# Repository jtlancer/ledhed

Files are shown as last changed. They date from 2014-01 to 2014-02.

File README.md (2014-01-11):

##Snoozerly Dawn Simulator
An Arduino-controlled combination [Ok to Wake](http://www.amazon.com/s/ref=nb_sb_noss?url=search-alias%3Daps&field-keywords=child%20ok%20to%20wake) alarm clock, [dawn simulator](http://www.amazon.com/Sunrise-Therapy-Light-Dawn-Simulator/dp/B0010AX7UY), and [PWM driver](http://www.amazon.com/LEDwholesalers-Dimming-Controller-LED-Lights/dp/B003L4KKF2/ref=pd_sim_hg_5).

###Components
* [16 ft Hitlits warm white LED strip light](http://www.amazon.com/Hitlights-Flexible-Ribbon-Adapter-included/dp/B005GL5UG2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) ([data sheet](http://www.hitlights.com/ls3528-30-group.html)) 
* ATmega328p
* [Maxim DS1388 RTC](http://www.digikey.com/product-detail/en/DS1388Z-33%2BT%26R/DS1388Z-33%2BT%26RCT-ND/4146799)
* [Nokia 5110 LCD module](http://www.ebay.com/bhp/nokia-5110)
* [Atmel AT42QT1070 capacitive touch sensor](http://www.digikey.com/product-detail/en/AT42QT1070-SSU%20QS529/AT42QT1070-SSU%20QS529CT-ND/2637953)

###Libraries in Repository

* [DS1307 RTC](https://github.com/adafruit/RTClib) Arduino library modified for the DS1388.

###Other Libraries
* [Eagle parts](https://github.com/jtlancer/jt_parts) customized from [Sparkfun](https://github.com/sparkfun/SparkFun-Eagle-Libraries) and [Adafruit](https://github.com/adafruit/Adafruit-Eagle-Library).
* Adafruit [PCD8544 Nokia 5110](https://github.com/adafruit/Adafruit-PCD8544-Nokia-5110-LCD-library) Arduino library.

##More Info
[crispytater.com](http://blog-crispytater.rhcloud.com/snoozerly-project/)

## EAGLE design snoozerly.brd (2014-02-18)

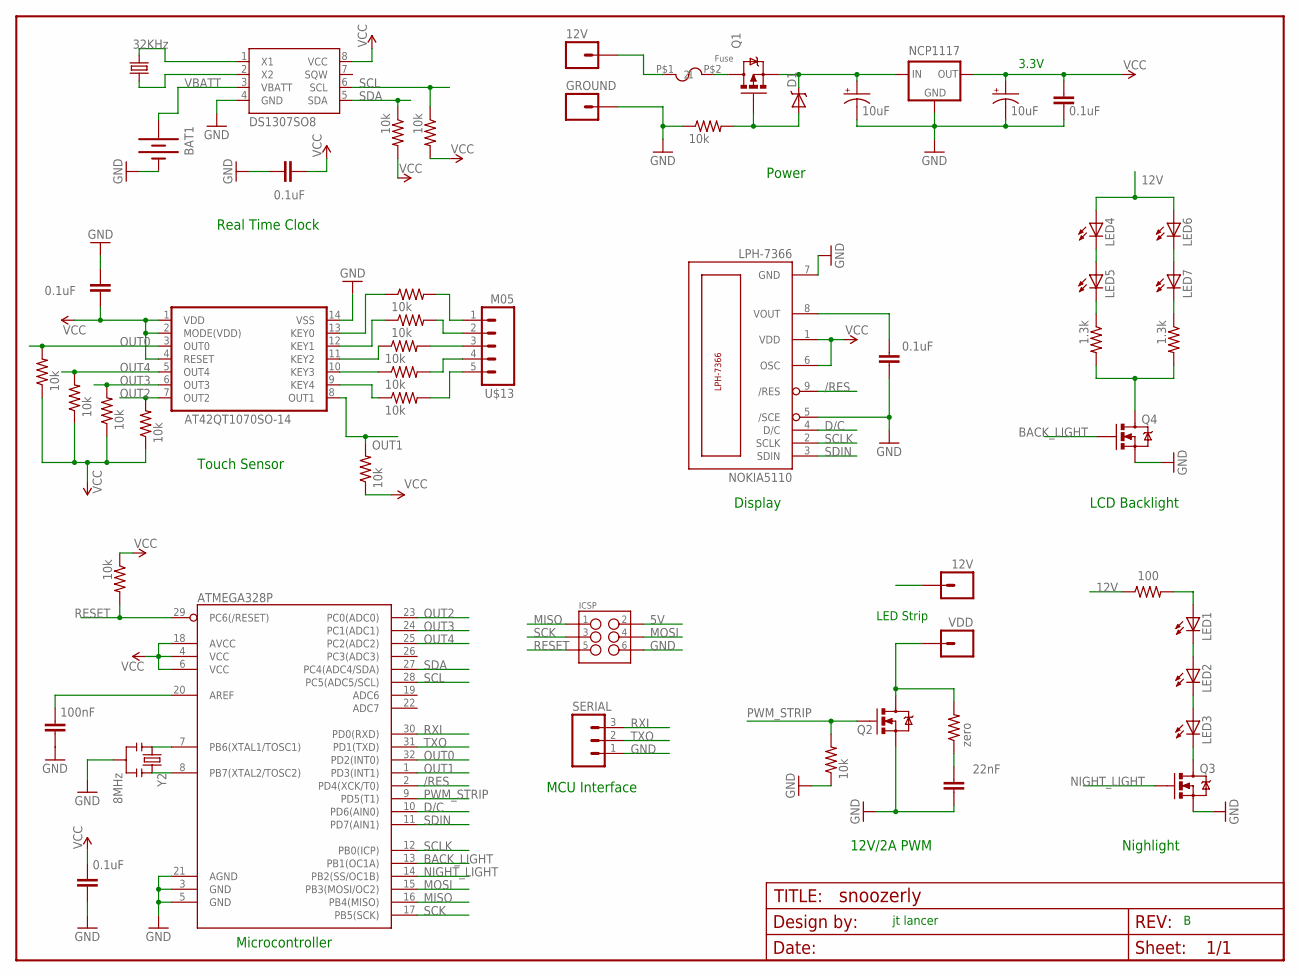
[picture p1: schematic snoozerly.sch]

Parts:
12V: M01; M01_BIGHOLE
AT42QT1070: AT42QT1070SO-14; SO-14
BAT1: BATTERY12MM; BATTCON_12MM
C1: 100nF; 0805
C2, C3, C6, C8, C9: 0.1uF; 0805
C4: 22nF; 0805
C5, C7: 10uF; CAP-PANASONIC-C
D1: DIODE-SCHOTTKYDO-214AA; DO-214AA
GROUND: M01; M01_BIGHOLE
ICSP: M03X2POGO_PINS; 2X3_POGO
LED1, LED2, LED3: LED; SIDEVIEW-LED
LED4, LED5, LED6, LED7: LED0603; LED-0603
NCP1117: VREG-3.3VNCP1117; TO-252
NOKIA5110: LPH-7366; NOKIA5110
Q1: MOSFET_PCHANNEL; DPAK
Q2: MOSFET-NCHANNELFDD8780; DPAK@1
Q3, Q4: MOSFET-NCHANNELBSS123LT1G; SOT23
SERIAL: M031X03_NO_SILK; 1X03_NO_SILK
U1: ATMEGA328P; TQFP32-08
U$1: FRAME_LETTER; CREATIVE_COMMONS
U$2, U$4, U$5, U$14, U$15: 10k; RESISTOR-0805
U$3: DS1307SO8; SO08
U$6, U$7, U$8, U$9, U$10, U$11, U$21, U$22, U$23, U$24: 10k; R0603
U$12: Fuse; FUSE-LITTLE-251
U$13: M05; M05-SMD
U$16: 100; RESISTOR-0805
U$17, U$18: 1.3k; RESISTOR-0805
U$25: zero; R0603
U$26: VDD; M01_BIGHOLE
U$27: 12V; M01_BIGHOLE
Y1: 32KHz; CRYSTAL-32KHZ-SMD
Y2: 8MHz; RESONATOR-SMD

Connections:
5V: AT42QT1070.1 (VDD), AT42QT1070.2 (MODE(VDD)), AT42QT1070.4 (RESET), C2.1, C3.1, C7.+, C8.1, C9.1, ICSP.P$2 (2), NCP1117.2 (OUT), NOKIA5110.1 (VDD), NOKIA5110.6 (OSC), U1.4 (VCC), U1.6 (VCC), U1.18 (AVCC), U$2.1, U$3.8 (VCC), U$4.2, U$5.2, U$6.1, U$21.1, U$22.1, U$23.1, U$24.1
12V: C5.+, D1.C, LED4.A, LED6.A, NCP1117.3 (IN), Q1.3 (S), U$16.1, U$27.1
/RES: NOKIA5110.9 (/RES), U1.2 (PD4(XCK/T0))
BACK_LIGHT: Q4.1 (G), U1.13 (PB1(OC1A))
D/C: NOKIA5110.4 (D/C), U1.10 (PD6(AIN0))
GND: AT42QT1070.14 (VSS), BAT1.GND (-), C1.2, C2.2, C3.2, C4.1, C5.-, C6.1, C7.-, C8.2, C9.2, GROUND.1, ICSP.P$6 (6), NCP1117.1 (GND), NOKIA5110.5 (/SCE), NOKIA5110.7 (GND), Q2.3 (S), Q3.2 (S), Q4.2 (S), SERIAL.1, U1.3 (GND), U1.5 (GND), U1.21 (AGND), U$3.4 (GND), U$14.1, U$15.1, Y2.2
KEY0: AT42QT1070.13 (KEY0), U$7.1
KEY1: AT42QT1070.12 (KEY1), U$8.1
KEY2: AT42QT1070.11 (KEY2), U$9.1
KEY3: AT42QT1070.10 (KEY3), U$10.1
KEY4: AT42QT1070.9 (KEY4), U$11.1
MISO: ICSP.P$1 (1), U1.16 (PB4(MISO))
MOSI: ICSP.P$4 (4), U1.15 (PB3(MOSI/OC2))
unnamed: U1.7 (PB6(XTAL1/TOSC1)), Y2.1
unnamed: LED7.C, U$18.1
unnamed: U1.8 (PB7(XTAL2/TOSC2)), Y2.3
unnamed: LED4.C, LED5.A
unnamed: U$3.1 (X1), Y1.X2 (2)
unnamed: U$3.2 (X2), Y1.X1 (1)
unnamed: 12V.1, U$12.P$1 (1)
unnamed: LED5.C, U$17.1
unnamed: Q4.3 (D), U$17.2, U$18.2
unnamed: C1.1, U1.20 (AREF)
unnamed: LED1.P$1 (A), U$16.2
unnamed: Q1.4 (D), U$12.P$2 (2)
unnamed: Q2.4 (D), U$25.2, U$26.1
unnamed: LED1.P$2 (C), LED2.P$1 (A)
unnamed: D1.A, Q1.1 (G), U$14.2
unnamed: LED6.C, LED7.A
unnamed: C4.2, U$25.1
unnamed: U$9.2, U$13.3
unnamed: C6.2, NOKIA5110.8 (VOUT)
unnamed: U$11.2, U$13.5
unnamed: LED2.P$2 (C), LED3.P$1 (A)
unnamed: U$10.2, U$13.4
unnamed: U$8.2, U$13.2
unnamed: U$7.2, U$13.1
unnamed: LED3.P$2 (C), Q3.3 (D)
NIGHT_LIGHT: Q3.1 (G), U1.14 (PB2(SS/OC1B))
OUT0: AT42QT1070.3 (OUT0), U1.32 (PD2(INT0)), U$6.2
OUT1: AT42QT1070.8 (OUT1), U1.1 (PD3(INT1)), U$23.2
OUT2: AT42QT1070.7 (OUT2), U1.23 (PC0(ADC0)), U$22.2
OUT3: AT42QT1070.6 (OUT3), U1.24 (PC1(ADC1)), U$21.2
OUT4: AT42QT1070.5 (OUT4), U1.25 (PC2(ADC2)), U$24.2
PWM_STRIP: Q2.1 (G), U1.9 (PD5(T1)), U$15.2
RESET: ICSP.P$5 (5), U1.29 (PC6(/RESET)), U$2.2
RXI: SERIAL.3, U1.30 (PD0(RXD))
SCK: ICSP.P$3 (3), U1.17 (PB5(SCK))
SCL: U1.28 (PC5(ADC5/SCL)), U$3.6 (SCL), U$5.1
SCLK: NOKIA5110.2 (SCLK), U1.12 (PB0(ICP))
SDA: U1.27 (PC4(ADC4/SDA)), U$3.5 (SDA), U$4.1
SDIN: NOKIA5110.3 (SDIN), U1.11 (PD7(AIN1))
TXO: SERIAL.2, U1.31 (PD1(TXD))
VBATT: BAT1.PWR@1 (+), U$3.3 (VBATT)

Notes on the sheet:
jt lancer
Real Time Clock
Touch Sensor
Microcontroller
MCU Interface
12V/2A PWM
Nighlight
LCD Backlight
Display
Power
3.3V
LED Strip

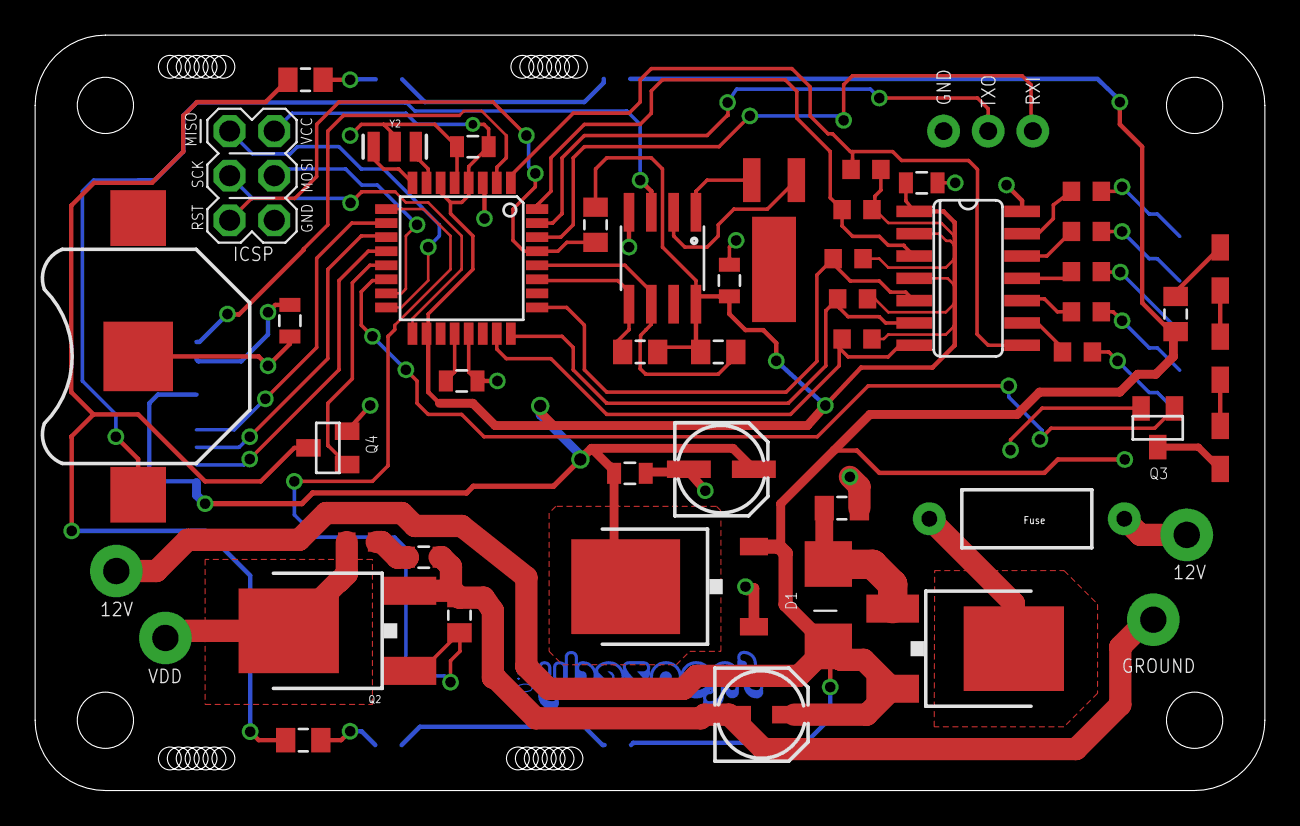
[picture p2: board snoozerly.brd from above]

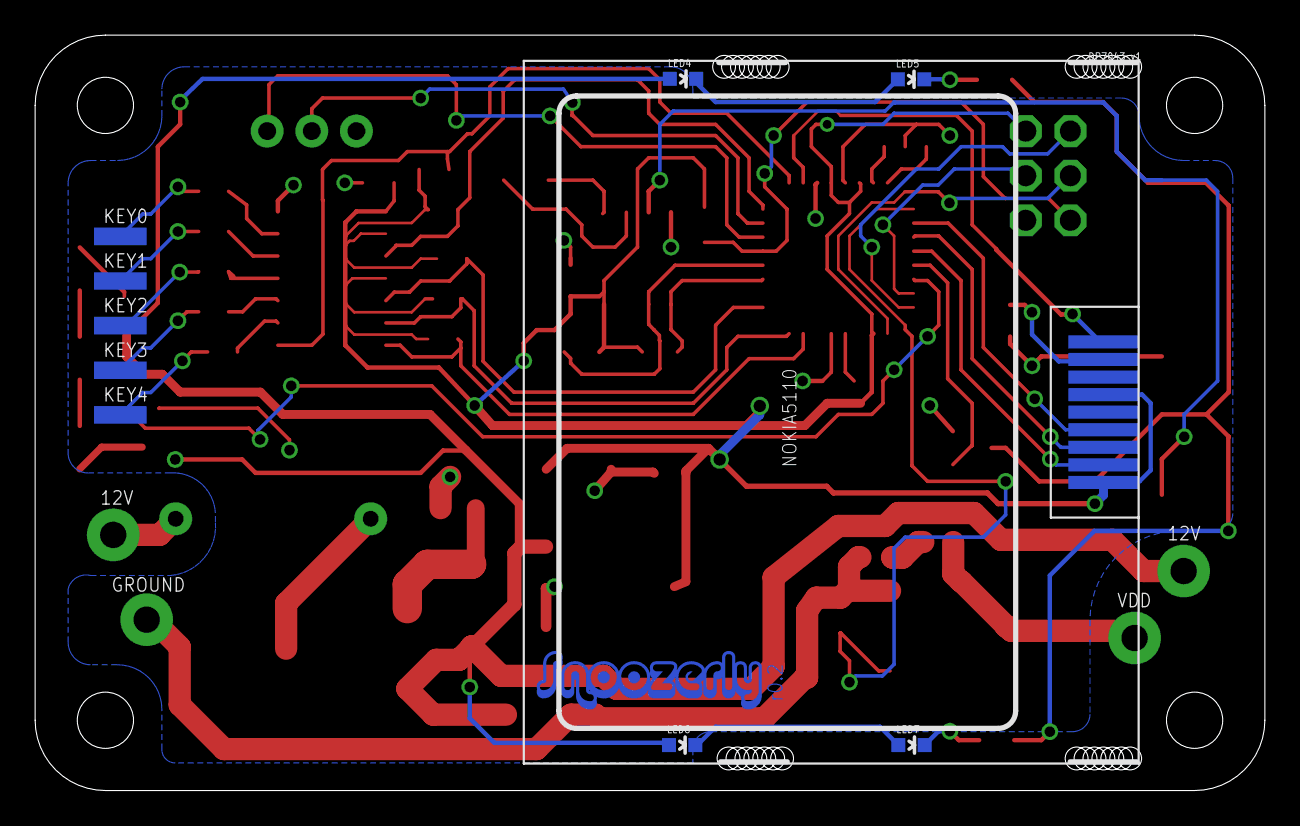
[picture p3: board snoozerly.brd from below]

Board: 2 copper layers, 70.0 x 43.0 mm, 59 parts (7 on the bottom side), 54 nets.

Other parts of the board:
U$19: SNOOZERLY_TOP
U$20: DP7043_V1

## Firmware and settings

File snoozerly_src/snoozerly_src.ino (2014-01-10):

#include <Wire.h>
#include <RTClib1388.h>
#include <Adafruit_GFX.h>
#include <Adafruit_PCD8544.h>
//#include <Time.h>
//#include <TimeAlarms.h>

RTC_DS1388 rtc;

int backlight_pin = 9;
int nightlight_pin = 10;
int ledstrip_pin = 5;

// led states
byte backlight_level = 0;
byte ledstrip_level = 0;
byte nightlight_level = 0;

// map key pins to a standard order (top, bottom, left, right)
// touch sensor key0 = pin 2 = bottom 
// touch sensor key1 = pin 3 = top
// touch sensor key2 = pin 14 = left
// touch sensor key3 = pin 15 = right
// touch sensor key4 = unused
#define NUM_KEY_PINS 4
int my_key_pins[4] = {3, 2, 14, 15};
// position of pin assignments in my_key_pins array
#define UP_KEY 0
#define DOWN_KEY 1
#define LEFT_KEY 2
#define RIGHT_KEY 3

// key states
unsigned long int old_key_time = millis();
int old_key = 0;

/////// nav tree /////////////////////////////////
// main screen items
#define ROOT_SCREEN 0
  #define ROOT_MANUAL_ITEM 1
  #define ROOT_SETTINGS_ITEM 0
  #define ROOT_NIGHTLIGHT_ITEM 2
// select settings screen items
#define SETTINGS_SCREEN 1
  #define SETTINGS_TIME_ITEM 0
  #define SETTINGS_ALARM_ITEM 1
  #define SETTINGS_ALARM_ENABLE_ITEM 2
  //#define SETTINGS_BACKLIGHT_ITEM 3
// adjust settings screen items
#define ADJUST_TIME_SCREEN 2
  #define ADJUST_TIME_HOUR_ITEM 0
  #define ADJUST_TIME_MINUTE_ITEM 1
  #define ADJUST_TIME_SAVE_ITEM 2
// adjust settings screen items
#define ADJUST_ALARM_SCREEN 3
  #define ADJUST_ALARM_HOUR_ITEM 0
  #define ADJUST_ALARM_MINUTE_ITEM 1
  //#define ADJUST_ALARM_DURATION_ITEM 2
  #define ADJUST_ALARM_SAVE_ITEM 2
#define ADJUST_ALARM_ENABLE_SCREEN 4
  #define ADJUST_ALARM_ENABLE_ITEM 0
//#define BACKLIGHT_SCREEN 5
  //#define ADJUST_BACKLIGHT_ITEM 0
  //#define ADJUST_BACKLIGHT_SAVE_ITEM 1
  
//int screen_items[5] = {3, 3, 3, 3, 1};
int active_screen = ROOT_SCREEN;
int active_item = ROOT_SETTINGS_ITEM;
boolean update_screen = true;

// time variables
DateTime time_last_update = 0;
int time_hour_temp = 999;
int time_minute_temp = 999;
int alarm_hour = 999;
int alarm_minute = 999;
int alarm_hour_temp = 999;
int alarm_minute_temp = 999;

// operating modes
// [0] = manual
// [1] = alarm
// [2] = nighlight
#define MANUAL_MODE 0
#define ALARM_MODE 1
#define NIGHTLIGHT_MODE 2
boolean active_mode[3] = {false, false, false};

// pin 8 - Serial clock out (SCLK)
// pin 7 - Serial data out (DIN)
// pin 6 - Data/Command select (D/C)
// none - LCD chip select (CS)
// pin 4 - LCD reset (RST)
Adafruit_PCD8544 display = Adafruit_PCD8544(8, 7, 6, 4);

///////////////////////////////////////////////////////////////////////

// the setup routine runs once when you press reset:
void setup() {                
  Serial.begin(1200);
  Wire.begin();
  display.begin();
  rtc.begin();  
  
  time_last_update = rtc.now();
  
  for(int i=0; i < NUM_KEY_PINS; i++) {
    pinMode(my_key_pins[i], INPUT);
  }
  
  pinMode(backlight_pin, OUTPUT);  
  pinMode(ledstrip_pin, OUTPUT);
  pinMode(nightlight_pin, OUTPUT);
  
  analogWrite(backlight_pin, backlight_level);
  analogWrite(ledstrip_pin, ledstrip_level);
  analogWrite(nightlight_pin, nightlight_level);
  
  display.begin();
  display.setContrast(52);
  display.clearDisplay();   // clears the screen and buffer
  display.display();
  
  // @@turn on screen backlight
  digitalWrite(backlight_pin, 125);
}

//////////////////////////////////////////////////////////////////////////////////////
////// Main Loop /////////////////////////////////////////////////////////////////////

void loop() {  
  ///////// check for new key press /////////////////////////////////
  int new_key = checkKeyPress();
  
  DateTime time_now = rtc.now();
  if ((time_now.minute() - time_last_update.minute()) >= 1) {
    update_screen = true;
    time_last_update = time_now;
  }
  
  //////////////////////////////////////////////////////////////////////////////////////
  ////// Root Screen ///////////////////////////////////////////////////////////////////
  ////////////////////////////////////////////////////////////////////////////////////// 
  if (active_screen == ROOT_SCREEN) {              
    if (active_item == ROOT_SETTINGS_ITEM) {
      
      if (new_key == my_key_pins[UP_KEY]) { // top button pressed, goto select screen
        active_screen = SETTINGS_SCREEN;
      } else if (new_key == my_key_pins[LEFT_KEY]) { // left button pressed, goto manual item
        active_item = ROOT_MANUAL_ITEM;
      } else if (new_key == my_key_pins[RIGHT_KEY]) { // right button pressed, goto nightlight
        active_item = ROOT_NIGHTLIGHT_ITEM;
      }            
  
      // update the screen if first loop, minutes changed, or arrived from another screen/item
      if (update_screen) {
        display.clearDisplay();
        display.display();
        
        display.setCursor(0,0);
        display.setTextColor(BLACK);
        display.setTextSize(1);
        display.println("- Main Menu -");
        
        display.setTextSize(2);
        display.print(time_now.hour(), DEC); 
        display.print(":");
        if (time_now.minute() < 10) {
          display.print("0");
          display.println(time_now.minute(), DEC);
        } else {
          display.println(time_now.minute(), DEC);
        }
        
        display.setTextSize(1);  
        if (active_mode[ALARM_MODE]) {
          display.println("( ( Alarm ) )"); 
        } else {
          display.println("x x Alarm x x");
        }        
        display.println("");
        
        display.print("ON-");
        display.setTextColor(WHITE, BLACK); // inverted text
        display.print(" SET ");
        display.setTextColor(BLACK);
        display.print("-NITE");
        display.display();
        
        update_screen = false;
      }
      
      if ((new_key == my_key_pins[UP_KEY]) || (new_key == my_key_pins[LEFT_KEY]) || (new_key == my_key_pins[RIGHT_KEY])) {
        update_screen = true;
      }
    ///////// Manual Item /////////////////////////////////////////////  
    } else if (active_item == ROOT_MANUAL_ITEM) {
     
        if (new_key == my_key_pins[UP_KEY]) {
          active_mode[0] = true; // ledstrip is in manual mode          
          if ((ledstrip_level + 5) <= 255) {
             ledstrip_level = ledstrip_level + 5;
             analogWrite(ledstrip_pin, ledstrip_level);
          }          
        } else if (new_key == my_key_pins[DOWN_KEY]) { 
           if ((ledstrip_level - 5) >= 0) {
             ledstrip_level = ledstrip_level - 5;
             analogWrite(ledstrip_pin, ledstrip_level);
           }           
           if (ledstrip_level == 0) {
             active_mode[0] = false; // manual_mode is false if pwm at zero
           }           
        } else if (new_key == my_key_pins[LEFT_KEY]) { // left button pressed, goto nightlight item      
          active_item = ROOT_NIGHTLIGHT_ITEM;
        } else if (new_key == my_key_pins[RIGHT_KEY]) { // right button pressed, goto setting item   
          active_item = ROOT_SETTINGS_ITEM;
        }
        
        // update the screen if first loop, minutes changed, or arrived from another screen/item
        if (update_screen) {
          display.clearDisplay();
          display.display();
          
          display.setCursor(0,0);
          display.setTextColor(BLACK);
          display.setTextSize(1);
          display.println("- Main Menu -");
          
          display.setTextSize(2);
          display.print(time_now.hour(), DEC); 
          display.print(":");
          if (time_now.minute() < 10) {
            display.print("0");
            display.println(time_now.minute(), DEC);
          } else {
            display.println(time_now.minute(), DEC);
          }
          
          display.setTextSize(1);
          if (active_mode[ALARM_MODE]) {
            display.println("( ( Alarm ) )");
          } else {
            display.println("");
          }     

          display.print("Manual ");       
          display.println(ledstrip_level);

          display.setTextSize(1);
          display.setTextColor(WHITE, BLACK); // inverted text
          display.print(" ON "); 
          display.setTextColor(BLACK);
          display.print("-SET");
          display.print("-NITE");
          display.display();
          
          update_screen = false;
        }
        
        if (new_key != 0) {
          update_screen = true;
        }  
    
    ///////// Nightlight Item /////////////////////////////////////////////    
    } else if (active_item == ROOT_NIGHTLIGHT_ITEM) {  
      active_mode[2] = true; // nighlight is on

      if (new_key == my_key_pins[UP_KEY]) {    
         if ((nightlight_level + 5) <= 255) {
           nightlight_level = nightlight_level + 5;
           analogWrite(nightlight_pin, nightlight_level);
         }
      } else if (new_key == my_key_pins[DOWN_KEY]) {    
         if ((nightlight_level - 5) >= 0) {
           nightlight_level = nightlight_level - 5;
           analogWrite(nightlight_pin, nightlight_level);
         }
      } else if (new_key == my_key_pins[LEFT_KEY]) {
        active_item = ROOT_SETTINGS_ITEM;
      }  else if (new_key == my_key_pins[RIGHT_KEY]) { 
        active_item = ROOT_MANUAL_ITEM;
      }
      
      // update the screen if first loop, minutes changed, or arrived from another screen/item
      if (update_screen) {
        display.clearDisplay();
        display.display();
        
        display.setCursor(0,0);
        display.setTextColor(BLACK);
        display.setTextSize(1);
        display.println("- Main Menu -");  
        
        display.setTextSize(2);
        display.print(time_now.hour(), DEC); 
        display.print(":");
        if (time_now.minute() < 10) {
          display.print("0");
          display.println(time_now.minute(), DEC);
        } else {
          display.println(time_now.minute(), DEC);
        }
        
        display.setTextSize(1);
        if (active_mode[ALARM_MODE]) {
          display.println("( ( Alarm ) )");
        } else {
          display.println("");
        }     

        display.print("Nitelite ");       
        display.println(nightlight_level);
        
        display.setTextSize(1);   
        display.print("ON"); 
        display.print("-SET-");
        display.setTextColor(WHITE, BLACK); // inverted text
        display.print(" NITE ");
        display.display();
    
        update_screen = false;    
      }
      
       if (new_key != 0) {
        update_screen = true;
      }
      
    }
    
  //////////////////////////////////////////////////////////////////////////////////////
  ////// Settigns Screens //////////////////////////////////////////////////////////////
  ////////////////////////////////////////////////////////////////////////////////////// 
  } else if (active_screen == SETTINGS_SCREEN) {

    //////////// Settings TIME Item /////////////////////////////////////////    
    if (active_item == SETTINGS_TIME_ITEM) {      
     time_hour_temp = 999;
     time_minute_temp = 999;
     
     if (new_key == my_key_pins[UP_KEY]) { // top button pressed
       active_screen = ADJUST_TIME_SCREEN;
       active_item = ADJUST_TIME_HOUR_ITEM;
     } else if (new_key == my_key_pins[LEFT_KEY]) { // left button pressed
       active_screen = ROOT_SCREEN;
     } else if (new_key == my_key_pins[RIGHT_KEY]) { // right button pressed
       active_item = SETTINGS_ALARM_ITEM;
     }            
  
      // update the screen if minutes changed or arrived from another screen/item
      if (update_screen) {
        display.clearDisplay();
        display.display();
        
        display.setCursor(0,0);
        display.setTextColor(BLACK);
        display.setTextSize(1);
        display.println("- Settings -");
        
        display.setTextSize(2);
        display.println("Adjust");
        display.println("Time"); 
     
       display.setTextSize(1);
        display.print(" << ");
        display.print(" SET ");
        display.print(" >> ");
        display.display();
        
        update_screen = false;
      }
      
      if ((new_key == my_key_pins[UP_KEY]) || (new_key == my_key_pins[LEFT_KEY]) || (new_key == my_key_pins[RIGHT_KEY])) {
        update_screen = true;
      }
    
    ///////////// Settings ALARM ////////////////////////////////////////////////  
    } else if (active_item == SETTINGS_ALARM_ITEM) {      
       alarm_hour_temp = 999;
       alarm_minute_temp = 999;
       
       if (new_key == my_key_pins[UP_KEY]) { // top button pressed, goto select screen
          active_screen = ADJUST_ALARM_SCREEN;
          active_item = ADJUST_ALARM_HOUR_ITEM;
        } else if (new_key == my_key_pins[LEFT_KEY]) { // left button pressed, goto manual item
          active_item = SETTINGS_TIME_ITEM;
        } else if (new_key == my_key_pins[RIGHT_KEY]) { // right button pressed, goto nightlight
          active_item = SETTINGS_ALARM_ENABLE_ITEM;
        }
   
        // update the screen if first loop, minutes changed, or arrived from another screen/item
        if (update_screen) {
          display.clearDisplay();
          display.display();
          
          display.setCursor(0,0);
          display.setTextColor(BLACK);
          display.setTextSize(1);
          display.println("- Settings -");
          
          display.setTextSize(2);
          display.println("Adjust");
          display.println("Alarm");
          
          display.setTextSize(1);
          display.print(" << ");
          display.print(" SET ");
          display.print(" >> ");
          display.display();
          
          update_screen = false;
        }
        
        if ((new_key == my_key_pins[UP_KEY]) || (new_key == my_key_pins[LEFT_KEY]) || (new_key == my_key_pins[RIGHT_KEY])) {
          update_screen = true;
        }
        
    ///////////// Settings ALARM ENABLE ////////////////////////////////////////////////         
    } else if (active_item == SETTINGS_ALARM_ENABLE_ITEM) {
      
       if (new_key == my_key_pins[UP_KEY]) { // top button pressed, goto select screen
          active_screen = ADJUST_ALARM_ENABLE_SCREEN;
          active_item = ADJUST_ALARM_ENABLE_ITEM;
        } else if (new_key == my_key_pins[LEFT_KEY]) { // left button pressed, goto manual item
          active_item = SETTINGS_ALARM_ITEM;
        }             
   
        // update the screen if first loop, minutes changed, or arrived from another screen/item
        if (update_screen) {
          display.clearDisplay();
          display.display();
          
          display.setCursor(0,0);
          display.setTextColor(BLACK);
          display.setTextSize(1);
          display.println("- Settings -");
          
          display.setTextSize(2);
          display.println("Enable");
          display.println("Alarm");
          
          display.setTextSize(1);
          display.print(" << ");
          display.print(" SET ");
          display.display();
          
          update_screen = false;
        }
        
        if ((new_key == my_key_pins[UP_KEY]) || (new_key == my_key_pins[LEFT_KEY])) {
          update_screen = true;
        }
    }
  
  //////////////////////////////////////////////////////////////////////////////////////
  ////// Adjustment Screens ////////////////////////////////////////////////////////////
  //////////////////////////////////////////////////////////////////////////////////////  
    
  ////////// Adjust Time Screen //////////////////////////////////  
  } else if (active_screen == ADJUST_TIME_SCREEN) {    
    if (time_hour_temp == 999) {
      time_hour_temp = time_now.hour(); 
    }
    if (time_minute_temp == 999) {
      time_minute_temp = time_now.minute();
    }    
    ////////// Adjust Time HOUR Item //////////////////////////////////
    if (active_item == ADJUST_TIME_HOUR_ITEM) {    
      
      
      
// @@@@@@ return properly formatted time items from subroutine @@@@@@@      
      
      
      
      
      
      if (new_key == my_key_pins[UP_KEY]) { // top button pressed, goto select screen
        if ((time_hour_temp + 1) < 24) {
          time_hour_temp++;        
        } else if ((time_hour_temp + 1) == 24){
          time_hour_temp = 0;
        }
      } else if (new_key == my_key_pins[DOWN_KEY]) {
        if ((time_hour_temp - 1) >= 0) {
          time_hour_temp--;        
        } else if (time_hour_temp == 0) {
          time_hour_temp = 23;
        }        
      } else if (new_key == my_key_pins[LEFT_KEY]) { // left button pressed, goto manual item
        active_screen = SETTINGS_SCREEN;
        active_item = SETTINGS_TIME_ITEM;
      } else if (new_key == my_key_pins[RIGHT_KEY]) { // right button pressed, goto nightlight
        active_item = ADJUST_TIME_MINUTE_ITEM;
      }            
  
      // update the screen if first loop, minutes changed, or arrived from another screen/item
      if (update_screen) {
        display.clearDisplay();
        display.display();
        
        display.setCursor(0,0);
        display.setTextColor(BLACK);
        display.setTextSize(1);
        display.println("- Set Time -");
        
        display.println("Adjust Hour");
        display.setTextSize(2);
        display.setTextColor(WHITE, BLACK); // inverted text
        display.print(time_hour_temp);  
        display.setTextColor(BLACK);
        display.print(":");
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

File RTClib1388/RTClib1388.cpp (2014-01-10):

// Code by JeeLabs http://news.jeelabs.org/code/
// Released to the public domain! Enjoy!

#include <Wire.h>
#include "RTClib1388.h"
#ifdef __AVR__
 #include <avr/pgmspace.h>
 #define WIRE Wire
#else
 #define PROGMEM
 #define pgm_read_byte(addr) (*(const unsigned char *)(addr))
 #define WIRE Wire1
#endif

#define DS1388_ADDRESS 0x68
#define SECONDS_PER_DAY 86400L

#define SECONDS_FROM_1970_TO_2000 946684800

#if (ARDUINO >= 100)
 #include <Arduino.h> // capital A so it is error prone on case-sensitive filesystems
#else
 #include <WProgram.h>
#endif

////////////////////////////////////////////////////////////////////////////////
// utility code, some of this could be exposed in the DateTime API if needed

const uint8_t daysInMonth [] PROGMEM = { 31,28,31,30,31,30,31,31,30,31,30,31 };

// number of days since 2000/01/01, valid for 2001..2099
static uint16_t date2days(uint16_t y, uint8_t m, uint8_t d) {
    if (y >= 2000)
        y -= 2000;
    uint16_t days = d;
    for (uint8_t i = 1; i < m; ++i)
        days += pgm_read_byte(daysInMonth + i - 1);
    if (m > 2 && y % 4 == 0)
        ++days;
    return days + 365 * y + (y + 3) / 4 - 1;
}

static long time2long(uint16_t days, uint8_t h, uint8_t m, uint8_t s) {
    return ((days * 24L + h) * 60 + m) * 60 + s;
}

////////////////////////////////////////////////////////////////////////////////
// DateTime implementation - ignores time zones and DST changes
// NOTE: also ignores leap seconds, see http://en.wikipedia.org/wiki/Leap_second

DateTime::DateTime (uint32_t t) {
  t -= SECONDS_FROM_1970_TO_2000;    // bring to 2000 timestamp from 1970

    ss = t % 60;
    t /= 60;
    mm = t % 60;
    t /= 60;
    hh = t % 24;
    uint16_t days = t / 24;
    uint8_t leap;
    for (yOff = 0; ; ++yOff) {
        leap = yOff % 4 == 0;
        if (days < 365 + leap)
            break;
        days -= 365 + leap;
    }
    for (m = 1; ; ++m) {
        uint8_t daysPerMonth = pgm_read_byte(daysInMonth + m - 1);
        if (leap && m == 2)
            ++daysPerMonth;
        if (days < daysPerMonth)
            break;
        days -= daysPerMonth;
    }
    d = days + 1;
}

DateTime::DateTime (uint16_t year, uint8_t month, uint8_t day, uint8_t hour, uint8_t min, uint8_t sec) {
    if (year >= 2000)
        year -= 2000;
    yOff = year;
    m = month;
    d = day;
    hh = hour;
    mm = min;
    ss = sec;
}

static uint8_t conv2d(const char* p) {
    uint8_t v = 0;
    if ('0' <= *p && *p <= '9')
        v = *p - '0';
    return 10 * v + *++p - '0';
}

// A convenient constructor for using "the compiler's time":
//   DateTime now (__DATE__, __TIME__);
// NOTE: using PSTR would further reduce the RAM footprint
DateTime::DateTime (const char* date, const char* time) {
    // sample input: date = "Dec 26 2009", time = "12:34:56"
    yOff = conv2d(date + 9);
    // Jan Feb Mar Apr May Jun Jul Aug Sep Oct Nov Dec 
    switch (date[0]) {
        case 'J': m = date[1] == 'a' ? 1 : m = date[2] == 'n' ? 6 : 7; break;
        case 'F': m = 2; break;
        case 'A': m = date[2] == 'r' ? 4 : 8; break;
        case 'M': m = date[2] == 'r' ? 3 : 5; break;
        case 'S': m = 9; break;
        case 'O': m = 10; break;
        case 'N': m = 11; break;
        case 'D': m = 12; break;
    }
    d = conv2d(date + 4);
    hh = conv2d(time);
    mm = conv2d(time + 3);
    ss = conv2d(time + 6);
}

uint8_t DateTime::dayOfWeek() const {    
    uint16_t day = date2days(yOff, m, d);
    return (day + 6) % 7; // Jan 1, 2000 is a Saturday, i.e. returns 6
}

uint32_t DateTime::unixtime(void) const {
  uint32_t t;
  uint16_t days = date2days(yOff, m, d);
  t = time2long(days, hh, mm, ss);
  t += SECONDS_FROM_1970_TO_2000;  // seconds from 1970 to 2000

  return t;
}

////////////////////////////////////////////////////////////////////////////////
// RTC_DS1388 implementation

static uint8_t bcd2bin (uint8_t val) { return val - 6 * (val >> 4); }
static uint8_t bin2bcd (uint8_t val) { return val + 6 * (val / 10); }

uint8_t RTC_DS1388::begin(void) {
  return 1;
}


#if (ARDUINO >= 100)

uint8_t RTC_DS1388::isrunning(void) {
  WIRE.beginTransmission(DS1388_ADDRESS);
  WIRE.write(0);
  WIRE.endTransmission();

  WIRE.requestFrom(DS1388_ADDRESS, 1);
  uint8_t ss = WIRE.read();
  return !(ss>>7);
}

void RTC_DS1388::adjust(const DateTime& dt) {
    WIRE.beginTransmission(DS1388_ADDRESS);
    WIRE.write(0);   
    WIRE.write(0);  // ADDED -- write 0 to hundredths of second
    WIRE.write(bin2bcd(dt.second()));
    WIRE.write(bin2bcd(dt.minute()));
    WIRE.write(bin2bcd(dt.hour()));
    WIRE.write(bin2bcd(0));
    WIRE.write(bin2bcd(dt.day()));
    WIRE.write(bin2bcd(dt.month()));
    WIRE.write(bin2bcd(dt.year() - 2000));
    WIRE.write(0);
    WIRE.endTransmission();
}

DateTime RTC_DS1388::now() {
  WIRE.beginTransmission(DS1388_ADDRESS);
  WIRE.write(0);	
  WIRE.endTransmission();

  //WIRE.requestFrom(DS1388_ADDRESS, 7);
  WIRE.requestFrom(DS1388_ADDRESS, 8); // CHANGED -- read 8 bytes from RTC
  WIRE.read();  // ADDED -- ignore the hundredths of seconds
  uint8_t ss = bcd2bin(WIRE.read() & 0x7F);
  uint8_t mm = bcd2bin(WIRE.read());
  uint8_t hh = bcd2bin(WIRE.read());
  WIRE.read();
  uint8_t d = bcd2bin(WIRE.read());
  uint8_t m = bcd2bin(WIRE.read());
  uint16_t y = bcd2bin(WIRE.read()) + 2000;
  
  return DateTime (y, m, d, hh, mm, ss);
}

#else

uint8_t RTC_DS1388::isrunning(void) {
  WIRE.beginTransmission(DS1388_ADDRESS);
  WIRE.send(0);	
  WIRE.endTransmission();

  WIRE.requestFrom(DS1388_ADDRESS, 1);
  uint8_t ss = WIRE.receive();
  return !(ss>>7);
}

void RTC_DS1388::adjust(const DateTime& dt) {
    WIRE.beginTransmission(DS1388_ADDRESS);
    WIRE.send(0);
    WIRE.send(0); // ADDED -- write 0 to hundredths of second
    WIRE.send(bin2bcd(dt.second()));
    WIRE.send(bin2bcd(dt.minute()));
    WIRE.send(bin2bcd(dt.hour()));
    WIRE.send(bin2bcd(0));
    WIRE.send(bin2bcd(dt.day()));
    WIRE.send(bin2bcd(dt.month()));
    WIRE.send(bin2bcd(dt.year() - 2000));
    WIRE.send(0);
    WIRE.endTransmission();
}

DateTime RTC_DS1388::now() {
  WIRE.beginTransmission(DS1388_ADDRESS);
  WIRE.send(0);	
  WIRE.endTransmission();
  
  //WIRE.requestFrom(DS1388_ADDRESS, 7);
  WIRE.requestFrom(DS1388_ADDRESS, 8); // CHANGED -- read first 8 bytes from RTC
  WIRE.receive();  // ADDED -- ignore the hundredths of second
  uint8_t ss = bcd2bin(WIRE.receive() & 0x7F);
  uint8_t mm = bcd2bin(WIRE.receive());
  uint8_t hh = bcd2bin(WIRE.receive());
  WIRE.receive();
  uint8_t d = bcd2bin(WIRE.receive());
  uint8_t m = bcd2bin(WIRE.receive());
  uint16_t y = bcd2bin(WIRE.receive()) + 2000;
  
  return DateTime (y, m, d, hh, mm, ss);
}

#endif


////////////////////////////////////////////////////////////////////////////////
// RTC_Millis implementation

long RTC_Millis::offset = 0;

void RTC_Millis::adjust(const DateTime& dt) {
    offset = dt.unixtime() - millis() / 1000;
}

DateTime RTC_Millis::now() {
  return (uint32_t)(offset + millis() / 1000);
}
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

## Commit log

2013-08-24 begin placing components to check fit
    [controller.brd, controller.sch]
2013-08-24 finished placing hour and minute leds
    [controller.brd, controller.sch]
2013-08-24 initial routing attempt for 24min/hour leds. forgot resistors!
    [controller.brd, controller.sch]
2013-08-25 added resistors. routed all leds.
    [controller.brd, controller.sch]
2013-08-25 changed board to 90 x 56
    [controller.brd, controller.sch]
2013-08-25 completed draft pcb layout for display board
    [controller.brd, controller.sch]
2013-08-26 fixed twisted nets in display schematic
    [controller.brd, controller.sch]
2013-08-26 Renamed controller > display. Removed resitor names. Added IC1 QH to IC2 serial.
    [display.brd, display.sch]
2013-09-01 first commit with controller board. layed out power section.
    [controller.brd, controller.sch]
2013-09-02 removed parts order from repo
    [controller.brd, controller.sch]
2013-09-03 reoriented controller to match with display.
    [controller.brd, controller.sch]
2013-09-03 fixed inconsistency between board and schematic.
    [controller.brd, controller.sch]
2013-09-04 began layout of mcu section
    [controller.brd, controller.sch]
2013-09-05 completed micro section schematic. split power from led strip pwm sections.
    [controller.brd, controller.sch]
2013-09-05 completed RTC and micro schematic. to do: switches
    [controller.brd, controller.sch, ds1307.brd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]
2013-09-06 Beginning of new controller board layout.
    [controller.brd, controller.sch, display.brd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]
2013-09-07 Layed out micro, jumpers, and rtc section.
    [controller.brd, controller.sch]
2013-09-07 controller board layout complete.
    [controller.brd, controller.sch]
2013-09-09 added fuse. tore up power traces.
    [controller.brd, controller.sch]
2013-09-12 commit prior to adding reverse polarity protection.
    [controller.brd, controller.sch]
2013-09-12 removed smaller board reference outline.
    [controller.brd]
2013-09-13 began moving controller to smaller board size.
    [controller.brd, controller.sch]
2013-09-18 added to do notes to schematic file.
    [controller.sch]
2013-09-18 removed totem pole, switches, encoder, and disaply board jumper.
    [controller.brd, controller.sch]
2013-09-23 changed to one board design.
    added LCD. added capacitive sense IC. changed to SMD programming
    header.
    [controller.brd, controller.sch, display.brd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]
2013-09-26 Layed out new power section. Some new digital routing. Added rt angle SMT LEDs.
    [controller.brd, controller.sch]
2013-09-27 added sense IC footprint and jumper. layed out "high" power section.
    [controller.brd, controller.sch]
2013-09-28 made 12V traces narrower. modified nokia5110 package.
    [controller.brd, controller.sch]
2013-09-29 decreased board size
    add backlight leds. changed to locking through hole programming header.
    reorganized and tightened voltage regulator section.
    [controller.brd, controller.sch]
2013-10-03 added current limit resistors. tightened rtc-mcu spacing.
    [controller.brd, controller.sch]
2013-10-05 wired lcd for software reset.
    [controller.brd, controller.sch]
2013-10-07 added sideview led footprint and replaced for night lights.
    [controller.brd, controller.sch]
2013-10-09 compacted layout. rerouted rtc. routed cap IC.
    [controller.brd, controller.sch]
2013-10-10 put leds in series. continue to tweak layout.
    [controller.brd, controller.sch]
2013-10-11 pre mod of power section
    [controller.brd]
2013-10-11 new power section layout.
    added leds to 12v rail.
    [controller.brd, controller.sch]
2013-10-12 all routing complete!
    [controller.brd, controller.sch]
2013-10-12 added gerbers
    [controller.brd]
2013-10-13 pre v0.1a branch
    [controller.brd]
2013-10-13 added board documentation
    [controller.brd, controller.sch]
2013-10-13 added logo and revision text to top layer
    [controller.brd]
2013-10-14 updated ground plane with curves and cutouts.
    [controller.brd]
2013-10-14 Added VCC test point and snoozerly graphic.
    [controller.brd, controller.sch]
2013-10-16 added status and power connectors, and lcd drill holes.
    [controller.brd, controller.sch]
2013-10-17 p-channel pad expanded
    [controller.brd]
2013-10-17 renamed board and schematic files
    [snoozerly.brd, snoozerly.sch]
2013-10-19 added output 0603 pullup resistors to touch sensor.
    [snoozerly.brd, snoozerly.sch]
2013-10-19 Added electrolytics and snubber jumper.
    [snoozerly.brd, snoozerly.sch]
2013-10-22 added top control board.
    [snoozerly.brd, snoozerly.sch]
2013-10-25 updated diode and SO-14 footprint
    [snoozerly.brd, snoozerly.sch]
2013-10-30 before remove daughter board
    [snoozerly.brd]
2013-10-31 before modifying vreg footprint
    [snoozerly.brd, snoozerly.sch]
2013-10-31 updated vreg pinouts/footprint and rerouted traces
    [snoozerly.brd, snoozerly.sch]
2013-10-31 update pchannel footprint and fixed spacings
    [snoozerly.brd, snoozerly.sch]
2013-11-17 fixed air wire to led strip mosfet
    [snoozerly.brd]
2013-11-17 fixed touch sensor vcc and gnd. increased docu fonts.
    [snoozerly.brd, snoozerly.sch]
2013-11-21 updates before touch sensor changes.
    [snoozerly.brd, snoozerly.sch]
2013-11-21 increase drill size change remaining.
    [snoozerly.brd, snoozerly.sch]
2013-11-27 increased 10uf cap pads
    [snoozerly.brd, snoozerly.sch]
2013-12-16 directory cleanup
    [ds1307.brd, ds1307.sch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]
2013-12-24 added snoozerly arduino source. moved to dropbox.
2013-12-28 fixed issue with clearing temp time hour/minute when exiting adjust mode. before implementing save time.
    [snoozerly_src.ino]
2014-01-09 updated sketch
    [snoozerly.brd, snoozerly.sch]
2014-01-10 added schematic pdf and RTClib for DS1388
    [snoozerly.sch]
2014-01-10 updated board file. added board pdf.
    [snoozerly.brd]
2014-02-15 before changing input/output power pads/holes
    [snoozerly.sch]
2014-02-16 added big power holes
    rerouted traces around corners. put test/prog headers on 0.1" center
    [snoozerly.brd, snoozerly.sch]
2014-02-18 complete rev 2 board for pcb order upload
    [snoozerly.brd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]

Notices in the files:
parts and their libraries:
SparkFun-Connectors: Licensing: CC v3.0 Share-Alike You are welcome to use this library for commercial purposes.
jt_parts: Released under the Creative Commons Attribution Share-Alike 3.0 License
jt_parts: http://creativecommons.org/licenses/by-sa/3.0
